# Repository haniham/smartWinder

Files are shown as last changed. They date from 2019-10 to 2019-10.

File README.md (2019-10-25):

# smartWinder
A module to smarten up "dumb" (non IOT-able) belt winders

The Project is based on the preliminary work in the FHEM forum which focused on connecting the existing GW60 electronic belt winder by Superrollo: https://forum.fhem.de/index.php/topic,60575.0.html
This repository is meant to keep the relevant information over the existing project and allow forther development.

# Working principle
The existing control unit was kept in place and extended with a secondary ESP8266 WiFi MCU.
Motion of the winder motor is fed in with 2 pins on the ESP.
The position can be determined via an magnetic sensor, either with the integrated hall sensor which is measuring the rotations of the winder or an additional placed hall Sensor which is measuring the rotations of the deflection roller.
The ESP gets control over the movement of the belt winder via two pins which simulate presses on the up and down key.

# Further ideas
- Extending more other comparably working belt winders
- Controlling other Devices which control the position of an object like Garage doors, etc.

# Credits
Great thanks to the FHEM community for all current and furher development and research on the topic https://forum.fhem.de/index.php/topic,60575.0.html

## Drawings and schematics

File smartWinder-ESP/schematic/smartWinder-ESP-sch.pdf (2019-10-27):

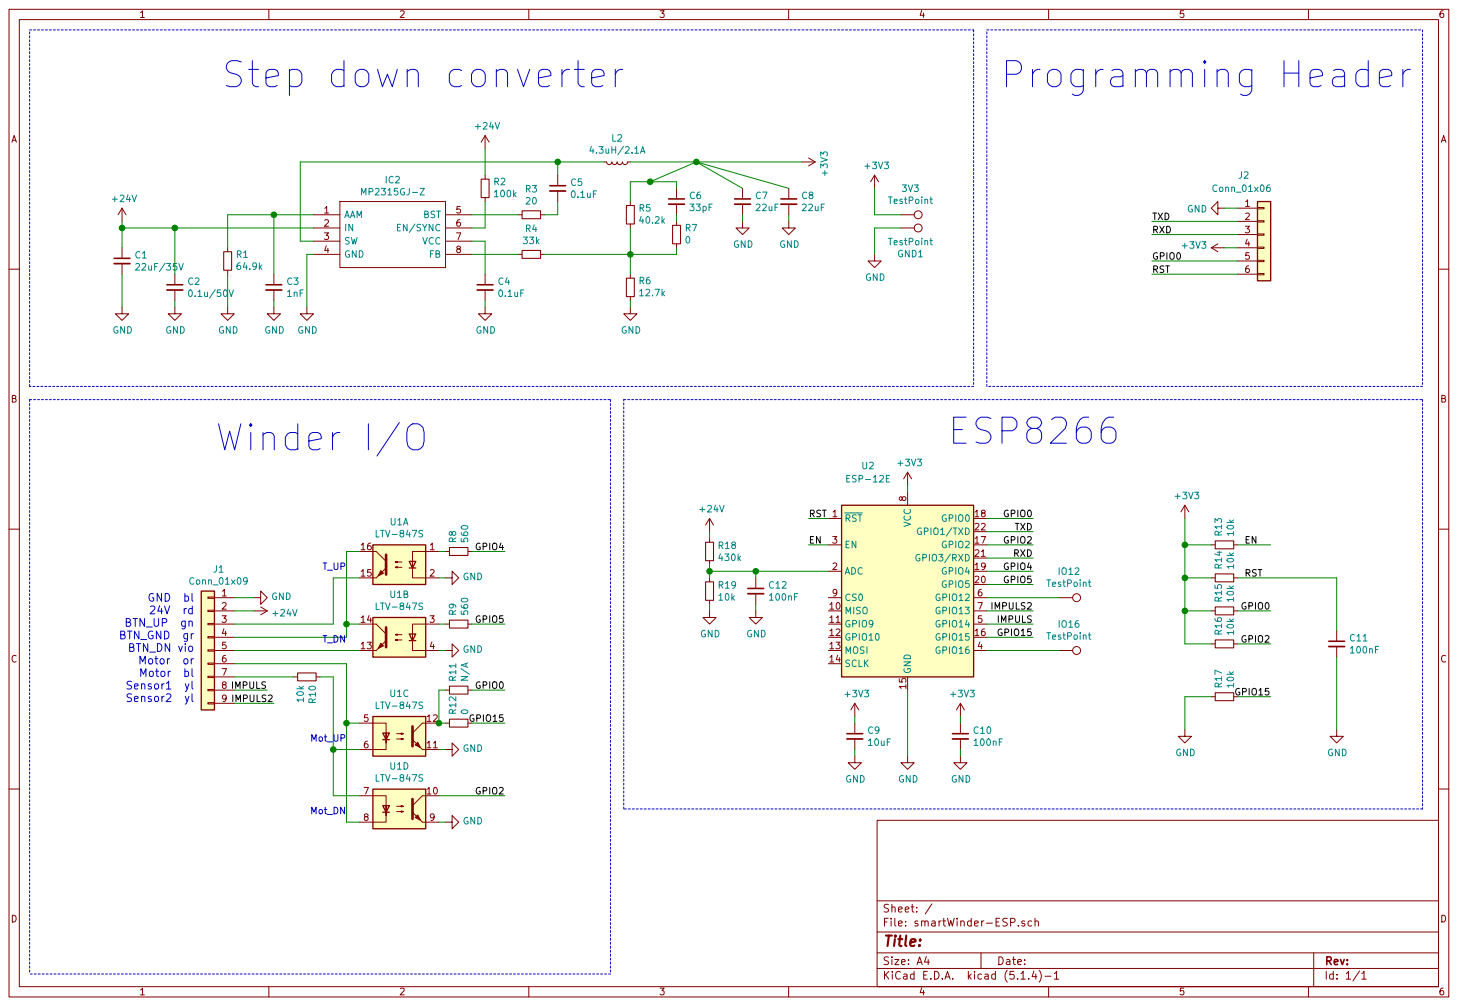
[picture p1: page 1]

Id: 1/1 Title: File: smartWinder-ESP.sch Sheet: /

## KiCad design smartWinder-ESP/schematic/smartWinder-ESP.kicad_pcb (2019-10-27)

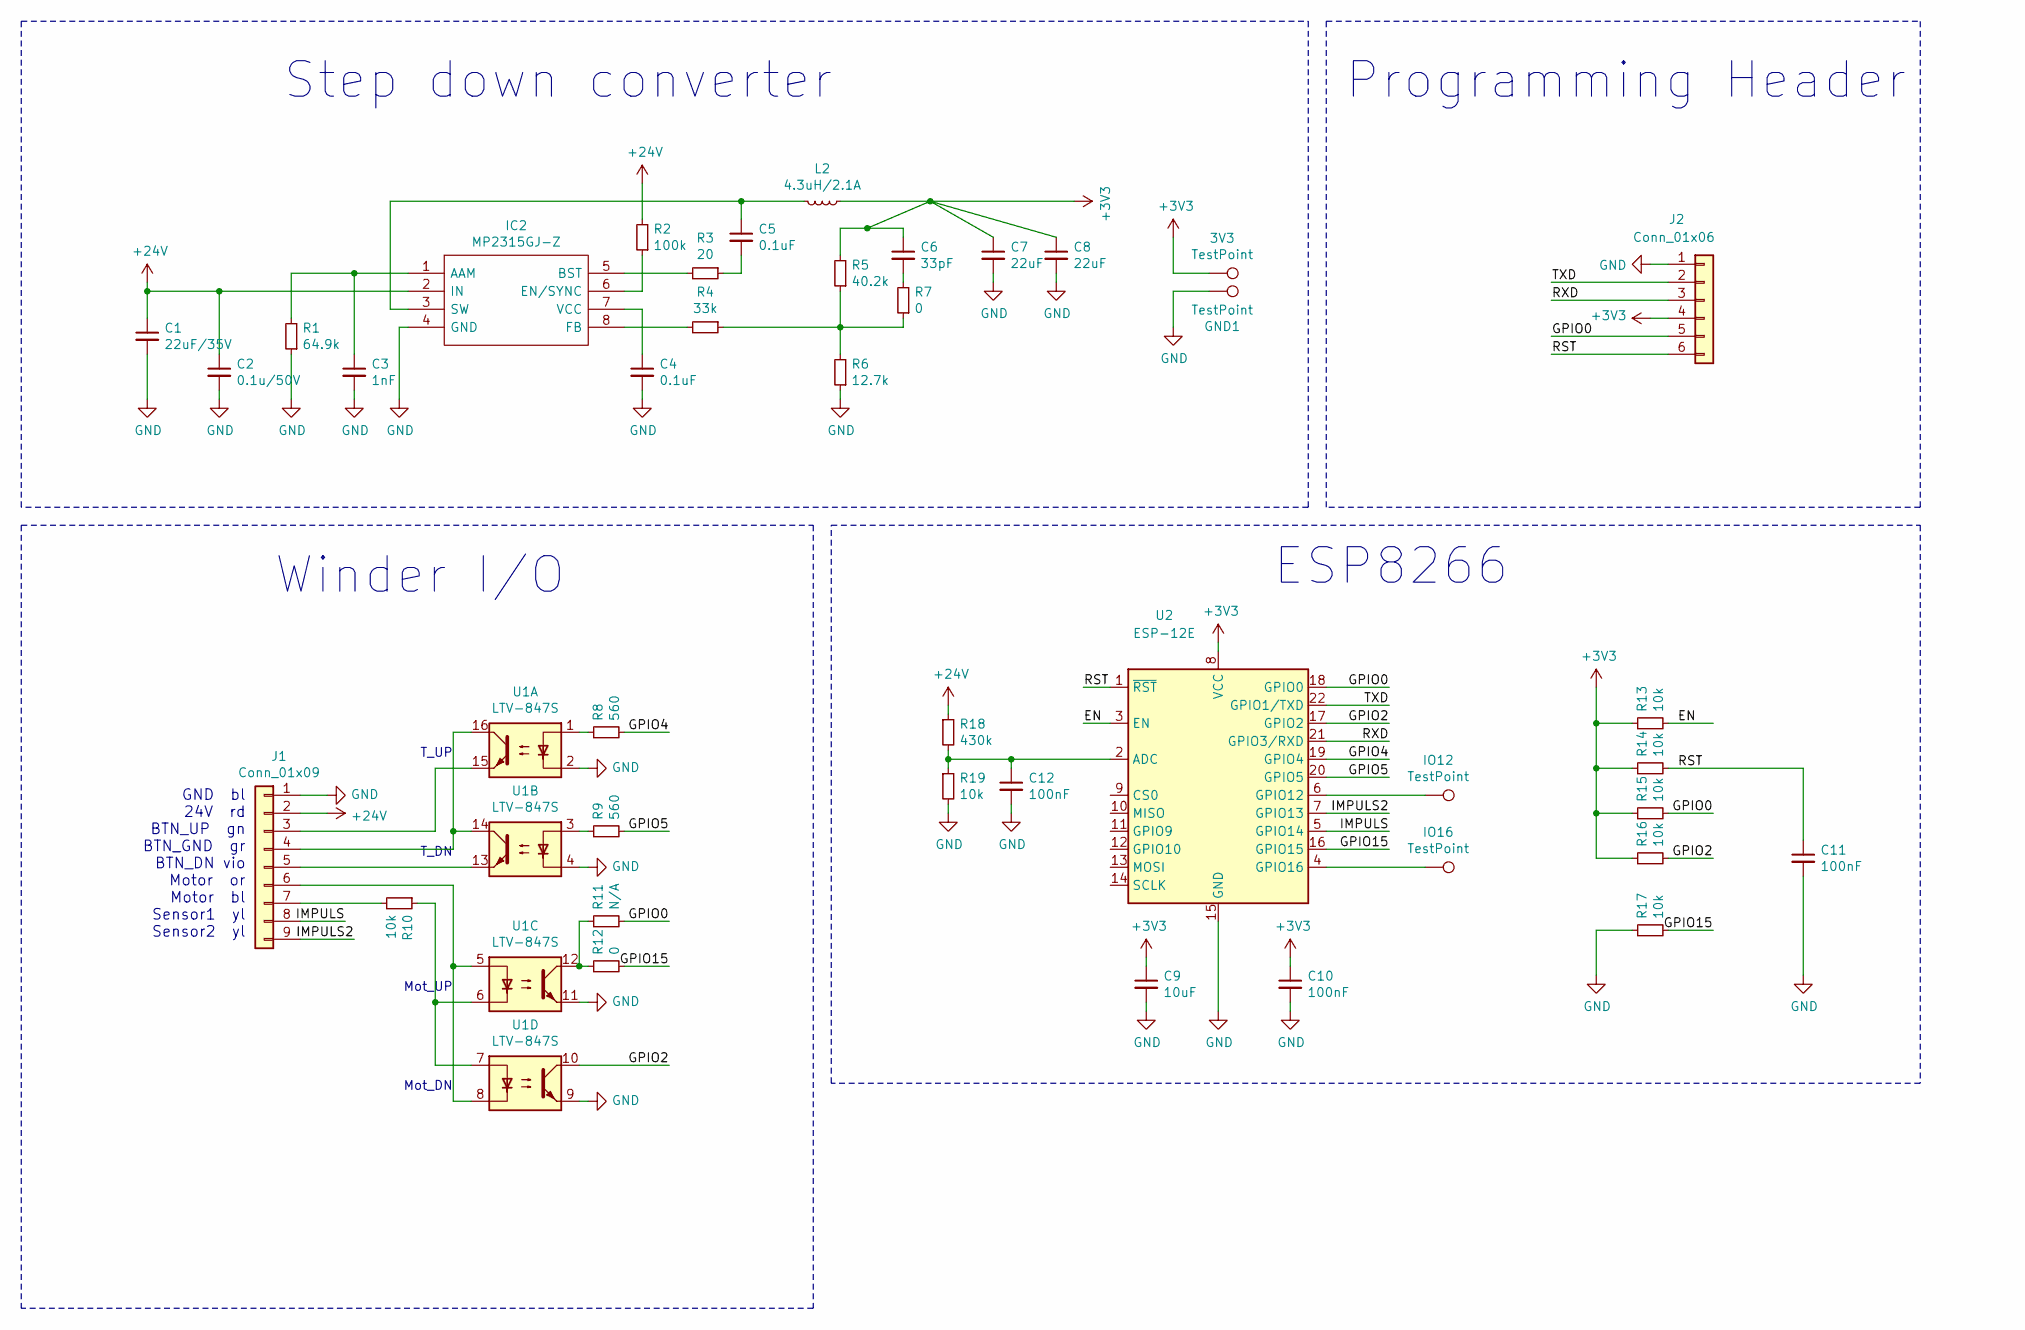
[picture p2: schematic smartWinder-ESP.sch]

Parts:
3V3: TestPoint; TestPoint_Pad_D1.0mm
C1: 22uF/35V; C_0805_2012Metric_Pad1.15x1.40mm_HandSolder
C2: 0.1u/50V; C_0805_2012Metric_Pad1.15x1.40mm_HandSolder
C3: 1nF; C_0805_2012Metric_Pad1.15x1.40mm_HandSolder
C4, C5: 0.1uF; C_0805_2012Metric_Pad1.15x1.40mm_HandSolder
C6: 33pF; C_0805_2012Metric_Pad1.15x1.40mm_HandSolder
C7, C8: 22uF; C_0805_2012Metric_Pad1.15x1.40mm_HandSolder
C9: 10uF; C_0805_2012Metric_Pad1.15x1.40mm_HandSolder
C10, C11, C12: 100nF; C_0805_2012Metric_Pad1.15x1.40mm_HandSolder
GND1: TestPoint; TestPoint_Pad_D1.0mm
IC2: MP2315GJ-Z; SOT65P280X100-8N; Manufacturer_Part_Number MP2315GJ-Z
IO12, IO16: TestPoint; TestPoint_Pad_D1.0mm
J1: Conn_01x09; PinHeader_1x09_P2.54mm_Vertical
J2: Conn_01x06; PinHeader_1x06_P2.54mm_Vertical
L2: 4.3uH/2.1A; L_6.3x6.3_H3
R1: 64.9k; R_0805_2012Metric_Pad1.15x1.40mm_HandSolder
R2: 100k; R_0805_2012Metric_Pad1.15x1.40mm_HandSolder
R3: 20; R_0805_2012Metric_Pad1.15x1.40mm_HandSolder
R4: 33k; R_0805_2012Metric_Pad1.15x1.40mm_HandSolder
R5: 40.2k; R_0805_2012Metric_Pad1.15x1.40mm_HandSolder
R6: 12.7k; R_0805_2012Metric_Pad1.15x1.40mm_HandSolder
R7, R12: 0; R_0805_2012Metric_Pad1.15x1.40mm_HandSolder
R8, R9: 560; R_0805_2012Metric_Pad1.15x1.40mm_HandSolder
R10, R13, R14, R15, R16, R17, R19: 10k; R_0805_2012Metric_Pad1.15x1.40mm_HandSolder
R11: N/A; R_0805_2012Metric_Pad1.15x1.40mm_HandSolder
R18: 430k; R_0805_2012Metric_Pad1.15x1.40mm_HandSolder
U1: LTV-847S; SMDIP-16_W9.53mm
U2: ESP-12E

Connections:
+3V3: 3V3.1, C6.1, C7.1, C8.1, C9.1, C10.1, J2.4, L2.1, R5.2, R13.1, R14.1, R15.1, R16.1, U2.8 (VCC)
+24V: C1.1, C2.1, IC2.2 (IN), J1.2, R2.2, R18.1
/EN: R13.2, U2.3 (EN)
/GPIO0: J2.5, R11.2, R15.2, U2.18 (GPIO0)
/GPIO2: R16.2, U1.10, U2.17 (GPIO2)
/GPIO4: R8.2, U2.19 (GPIO4)
/GPIO5: R9.2, U2.20 (GPIO5)
/GPIO15: R12.2, R17.2, U2.16 (GPIO15)
/IMPULS: J1.8, U2.5 (GPIO14)
/IMPULS2: J1.9, U2.7 (GPIO13)
/RST: C11.1, J2.6, R14.2, U2.1 (~RST)
/RXD: J2.3, U2.21 (GPIO3/RXD)
/TXD: J2.2, U2.22 (GPIO1/TXD)
GND: C1.2, C2.2, C3.2, C4.2, C7.2, C8.2, C9.2, C10.2, C11.2, C12.2, GND1.1, IC2.4 (GND), J1.1, J2.1, R1.1, R6.1, R17.1, R19.2, U1.2, U1.4, U1.9, U1.11, U2.15 (GND); also elsewhere on the board
unnamed: C3.1, IC2.1 (AAM), R1.2
unnamed: C4.1, IC2.7 (VCC)
unnamed: C5.1, IC2.3 (SW), L2.2
unnamed: C5.2, R3.1
unnamed: C6.2, R7.2
unnamed: C12.1, R18.2, R19.1, U2.2 (ADC)
unnamed: IC2.5 (BST), R3.2
unnamed: IC2.6 (EN/SYNC), R2.1
unnamed: IC2.8 (FB), R4.2
unnamed: IO12.1, U2.6 (GPIO12)
unnamed: IO16.1, U2.4 (GPIO16)
unnamed: J1.3, U1.15
unnamed: J1.4, U1.14, U1.16
unnamed: J1.5, U1.13
unnamed: J1.6, U1.5, U1.8
unnamed: J1.7, R10.2
unnamed: R4.1, R5.1, R6.2, R7.1
unnamed: R8.1, U1.1
unnamed: R9.1, U1.3
unnamed: R10.1, U1.6, U1.7
unnamed: R11.1, R12.1, U1.12

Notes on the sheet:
GND bl 24V rd BTN_UP gn BTN_GND gr BTN_DN vio Motor or Motor bl Sensor1 yl Sensor2 yl
T_UP
T_DN
Mot_UP
Mot_DN
Step down converter
Programming Header
Winder I/O
ESP8266

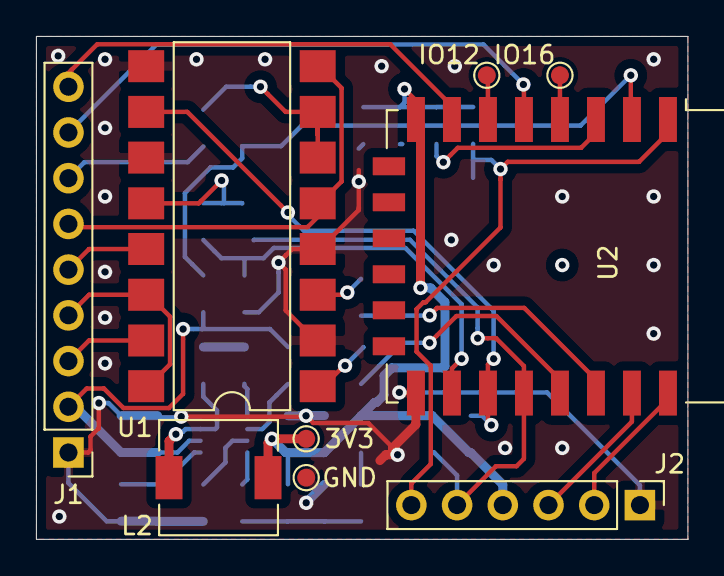
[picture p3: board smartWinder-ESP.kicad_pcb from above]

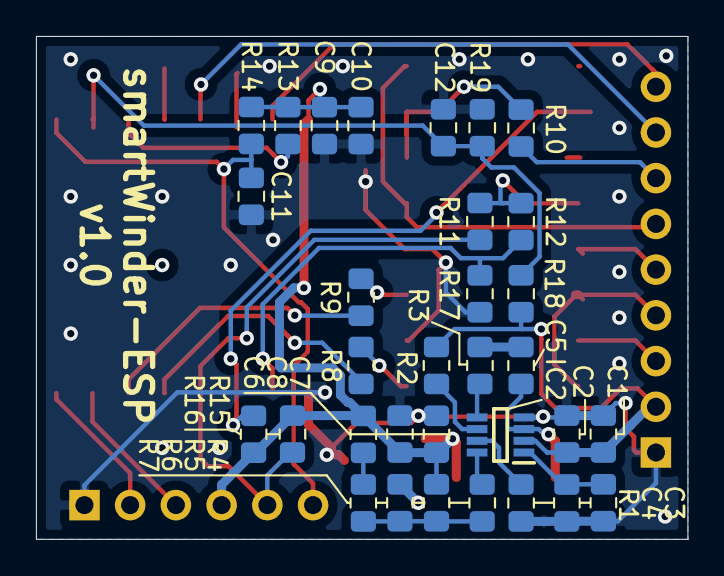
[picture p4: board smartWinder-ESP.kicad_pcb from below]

Board: 2 copper layers, 36.2 x 27.9 mm, 41 parts (32 on the bottom side), 35 nets.

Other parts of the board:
GND: TestPoint; TestPoint_Pad_D1.0mm

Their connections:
GND: GND.1; also elsewhere on the board

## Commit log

2019-10-26 Created Schematic
    [smartWinder-ESP.kicad_pcb, smartWinder-ESP.sch]
2019-10-27 Added VIN Sensing to the PCB
    [smartWinder-ESP.kicad_pcb, smartWinder-ESP.sch]
2019-10-27 Finalized PCB and sent to Production
    Finalized PCB and sent to Production
    Generated PDF and 3D PCB File
    [smartWinder-ESP.kicad_pcb, smartWinder-ESP.sch]
2019-10-27 Merged finalized PCB Design in master branch
